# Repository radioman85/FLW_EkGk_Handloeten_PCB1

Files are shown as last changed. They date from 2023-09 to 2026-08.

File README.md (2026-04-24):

### Präsentation
[FabLab - Handlötkurs 02-2025.pdf](https://github.com/user-attachments/files/19078771/FabLab.-.Handlotkurs.02-2025.pdf)

### BOM

Currently unavailable

### Programming Pi Pico

## Preparation

1. Download, install and run the [thonny app](https://thonny.org/)
2. Connect the pico
3. In the Thonny app on the right bottom corner you can see your connected pico. From there install the micro python firmware

## Python Script
1. Once the pico has received its micro python firmware click on the "Stop" button on top of the thonny app.
5. Load the script you want to download to the raspi.
6. Go to "Save as", where it asks for either save on PC or on Raspberry (if not asked, the raspberry is not connected correctly (its firmware may not be up-to-date)).
7. Select "Raspberry Pi".
8. Save it as "main.py" (it must be named as "main" else it wont auto-start after reboot)
9. Happy running :-)

### Löten - Ausrüstung

 - Lötkolben (Link: [JBC CD-2BQF](https://shop.electronic-metals.ch/produkte/loettechnik/loetgeraete-ein-kanal/jbc/94951/jbc-kompakt-loetstation-cd-2bqf-wetec-edition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), Handle (included): [T245](https://www.jbctools.com/t245-general-purpose-handle-product-45.html) , Spitzen (NOT included): [C245-030](https://shop.electronic-metals.ch/produkte/loettechnik/loet-entloetspitzen/jbc/c245-fuer-t245/rundform/8647/jbc-loetspitze-serie-c245-rundform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), -034, -906)
 - Lötzinn + Paste
    - 63% (Sn), 37% (Pb) (Link: [Lötdraht 0.7 mm](https://ch.farnell.com/multicore-loctite/d610scf222-250g/l-tdraht-60-40-0-7mm-250g/dp/454072), Link: [Paste - Chip Quik SMD291AX](https://ch.farnell.com/chip-quik/smd291ax/l-tpaste-no-clean-synthetisch/dp/3549310)) oder
    - 95,5% (Sn), 3,8% (Ag), 0,7% (Cu) (Link: [Lötdraht 0.7 mm](https://ch.farnell.com/multicore-loctite/d96scf222-250g/l-tdraht-105-0-7mm-250g/dp/454590), Link: [Chip Quik TS391SNL](https://ch.farnell.com/chip-quik/ts391snl/l-tpaste-no-clean-synthetisch/dp/3549323))
 - Lötflussmittel (Link: [Chip Quik SMD291](https://www.mouser.ch/ProductDetail/Chip-Quik/SMD291?qs=8BX3xQzFIvmwkympZqnNNA%3D%3D))
 - Lötmatte
 - Pinzetten (Link: [Weller Erem 7SASL, gebogen](https://ch.farnell.com/erem/7sasl/pr-zisionspinzette-gebogen-spitz/dp/2946763), Link: [Weller Erem 3SASL, gerade](https://ch.farnell.com/erem/3sasl/pinzette-120mm/dp/1014352))
 - Zahbüsrteli / Wattestäbli (Link: [M-Budget Zahnbürste](https://www.migros.ch/de/product/mo/96751))
 - Fläschli Isopropanol (Link: [Isopropanol 99,9 %](https://www.gerstaecker.ch/Isopropanol-99-9.html))
 - Shimblade (Link: [EDSYN - ST706](https://ch.farnell.com/edsyn/st706/halter-f-r-entl-tklingen/dp/844457), Ersatzklingen (Link: [EDSYN - RB641](https://ch.farnell.com/edsyn/rb641/entl-tklingen-zuschneidbares-stahlband/dp/844445))
 - Tip Tinner/Cleaner/Activator (Link: [Weller Tip Activater](https://www.simpex.ch/shop/produktionstechnik/loetzubehoer/tip-aktivator-bleifrei/?gad_campaignid=22242456144))

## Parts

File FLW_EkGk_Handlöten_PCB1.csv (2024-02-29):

Source: | C:\98-Others\FLW_EkGk_Handloeten_PCB1\FLW_EkGk_Handlöten_PCB1.kicad_sch
Date: | 21-Nov-23 21:35:43
Tool: | Eeschema 7.0.1
Generator: | C:\Program Files\KiCad\7.0\bin\scripting\plugins/bom_csv_grouped_by_value.py
Component Count: | 110
Collated Components:
Item | Qty | Reference(s) | Value | LibPart | Footprint | Datasheet | DNP | Country of Origin | Function | Height | Manufacturer_Name | Manufacturer_Part_Number | Mouser Part Number | Mouser Price/Stock | Voltage
1 | 2 | C61, C62 | 100n | Device:C | Capacitor_SMD:C_1206_3216Metric | ~
2 | 1 | IC60 | HCF4094YM013TR | :HCF4094YM013TR_1 | NiksKiCadLibrary:SOIC-16-SOIC127P600X175-16N | http://www.st.com/st-web-ui/static/active/en/resource/technical/document/datasheet/CD00000399.pdf |  |  |  | 1.75 | STMicroelectronics | HCF4094YM013TR | 511-HCF4094YM013TR | https://www.mouser.co.uk/ProductDetail/STMicroelectronics/HCF4094YM013TR?qs=wkiPY8TIIKfZLRSu0KejOg%3D%3D | Vin: 3 ... 20 V
3 | 1 | IC61 | HCF4094YM013TR | NiksKiCadLibrary:HCF4094YM013TR | NiksKiCadLibrary:SOIC-16-SOIC127P600X175-16N | http://www.st.com/st-web-ui/static/active/en/resource/technical/document/datasheet/CD00000399.pdf |  |  |  | 1.75 | STMicroelectronics | HCF4094YM013TR | 511-HCF4094YM013TR | https://www.mouser.co.uk/ProductDetail/STMicroelectronics/HCF4094YM013TR?qs=wkiPY8TIIKfZLRSu0KejOg%3D%3D | Vin: 3 ... 20 V
4 | 4 | J10, J11, J12, J13 | Conn_01x02 | Connector_Generic:Conn_01x02 | Connector_PinHeader_2.54mm:PinHeader_1x02_P2.54mm_Horizontal | ~
5 | 13 | LED60, LED61, LED62, LED63, LED64, LED65, LED69, LED70, LED71, LED72, LED73, LED74, LED75 | SML-LX1206SIC-TR | FabLabWintiLibrary:SML-LX1206SIC-TR | FabLabWintiLibrary:LED_SML-LX1206SIC-TR_LUM | SML-LX1206SIC-TR
6 | 3 | LED66, LED67, LED68 | LTST-E563CEGBW | NiksKiCadLibrary:LTST-E563CEGBW | NiksKiCadLibrary:LTSTE563CEGBW | https://optoelectronics.liteon.com/upload/download/DS35-2018-0038/LTST-E563CEGBW.PDF |  | China |  | 1.62 | Lite-On | LTST-E563CEGBW | 859-LTST-E563CEGBW
7 | 13 | Q60, Q61, Q62, Q63, Q64, Q65, Q66, Q67, Q68, Q69, Q70, Q71, Q72 | 2N7002 | Transistor_FET:2N7002 | Package_TO_SOT_SMD:SOT-23 | https://www.onsemi.com/pub/Collateral/NDS7002A-D.PDF
8 | 33 | R10, R11, R12, R13, R14, R15, R16, R17, R18, R19, R30, R31, R32, R33, R34, R35, R36, R37, R38, R39, R60, R61, R62, R63, R64, R65, R67, R68, R69, R70, R71, R72, R73 | R | Device:R | Resistor_SMD:R_1206_3216Metric | ~
9 | 20 | R20, R21, R22, R23, R24, R25, R26, R27, R28, R29, R40, R41, R42, R43, R44, R45, R46, R47, R48, R49 | R | Device:R | Resistor_SMD:R_0805_2012Metric | ~
10 | 2 | R66, R74 | 330R | Device:R | Resistor_SMD:R_1206_3216Metric | ~
11 | 4 | R75, R76, R77, R78 | 10k | Device:R | Resistor_SMD:R_1206_3216Metric | ~
12 | 1 | SW60 | MSS6-V-T_R | NiksKiCadLibrary:MSS6-V-T_R | NiksKiCadLibrary:MSS6VTR | http://www.dip.com.tw/en/en-product-information/en-switch005/item/download/2644_d484074ddae8110c965b39aa743c4160 |  |  | Power Enable | 2.9 | Diptronics | MSS6-V-T/R | 113-MSS6-V-T/R | https://www.mouser.co.uk/ProductDetail/Diptronics/MSS6-V-T-R?qs=gTYE2QTfZfT81btvsnXi7w%3D%3D
13 | 1 | SW61 | B3U-3100P | :B3U-3100P_1 | SW_B3U-3100P_OMR | B3U-3100P |  |  | Manual Clock
14 | 1 | SW62 | B3U-3100P | NiksKiCadLibrary:B3U-3100P | SW_B3U-3100P_OMR | B3U-3100P |  |  | Manual Data
15 | 10 | TP60, TP61, TP62, TP63, TP64, TP65, TP66, TP67, TP68, TP69 | TestPoint | Connector:TestPoint | NiksKiCadLibrary:TestPointSimpleSMD | ~
16 | 1 | U2 | RPi-Pico | FabLabWintiLibrary:RPi-Pico | FabLabWintiLibrary:RPi_Pico_SMD_TH

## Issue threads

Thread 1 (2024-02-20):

RGB-LED Footprint too small

radioman85, 2024-02-20:

Closed 2024-02-29.

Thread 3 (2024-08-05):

RGB LED: Missing Pin Mark

radioman85, 2024-08-05:

Closed 2024-09-02.

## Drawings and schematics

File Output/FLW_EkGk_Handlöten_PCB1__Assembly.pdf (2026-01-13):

LED0 Data | þÿLötkurs - | þÿHandlöten
1 | 3 | 4 Clock PulsePraxis 1 - | Erste | þÿLötstellen

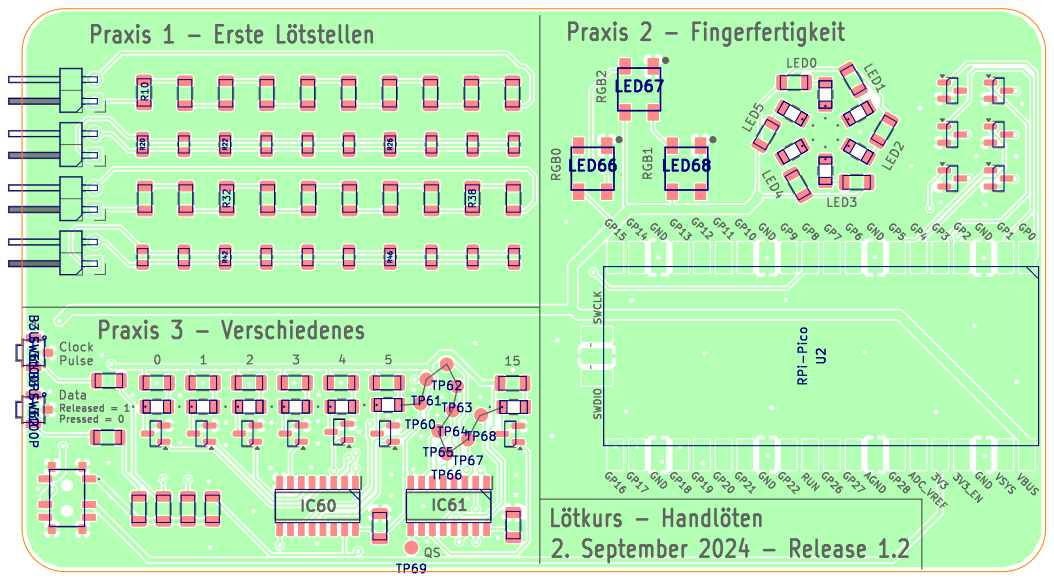
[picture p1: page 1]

Id: /1 Title: File: þÿFLW_EkGk_Handlöten_PCB1.kicad_pcb Sheet: Colored TOP

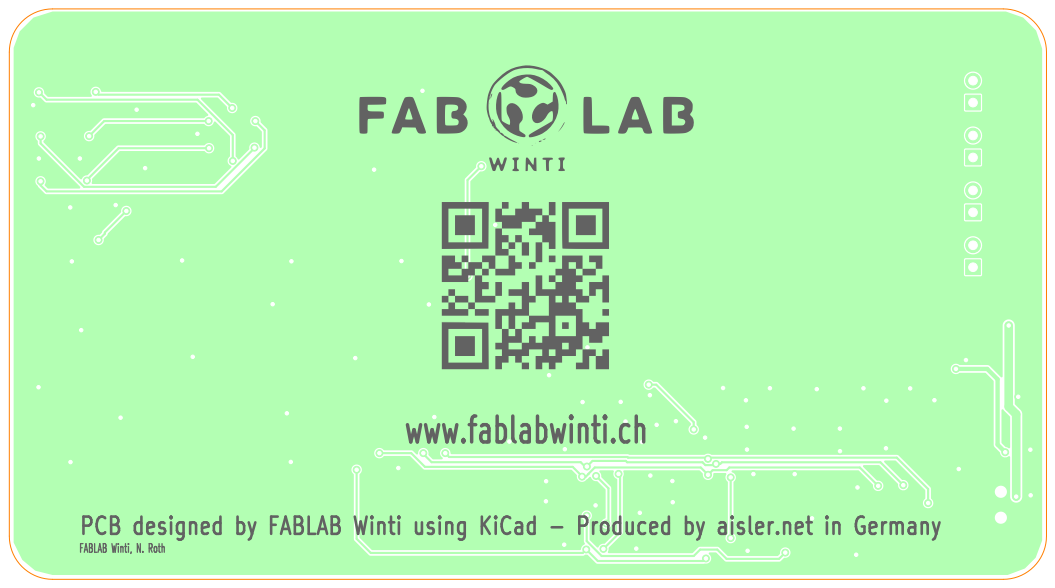
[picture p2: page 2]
PCB designed; FABLAB; Winti using KiCad; Produced by; aisler.net in Germany; FABLAB Winti, N. Roth; www.fablabwinti.ch; D Date: KiCad; E.D.A. 9.0.0 Size: A4; Rev:; Id: /1 Title: File: þÿFLW_EkGk_Handlöten_PCB1.kicad_pcb Sheet: Colored; BOT Board2Pdf:; Colored; BOT -; Page 2/2

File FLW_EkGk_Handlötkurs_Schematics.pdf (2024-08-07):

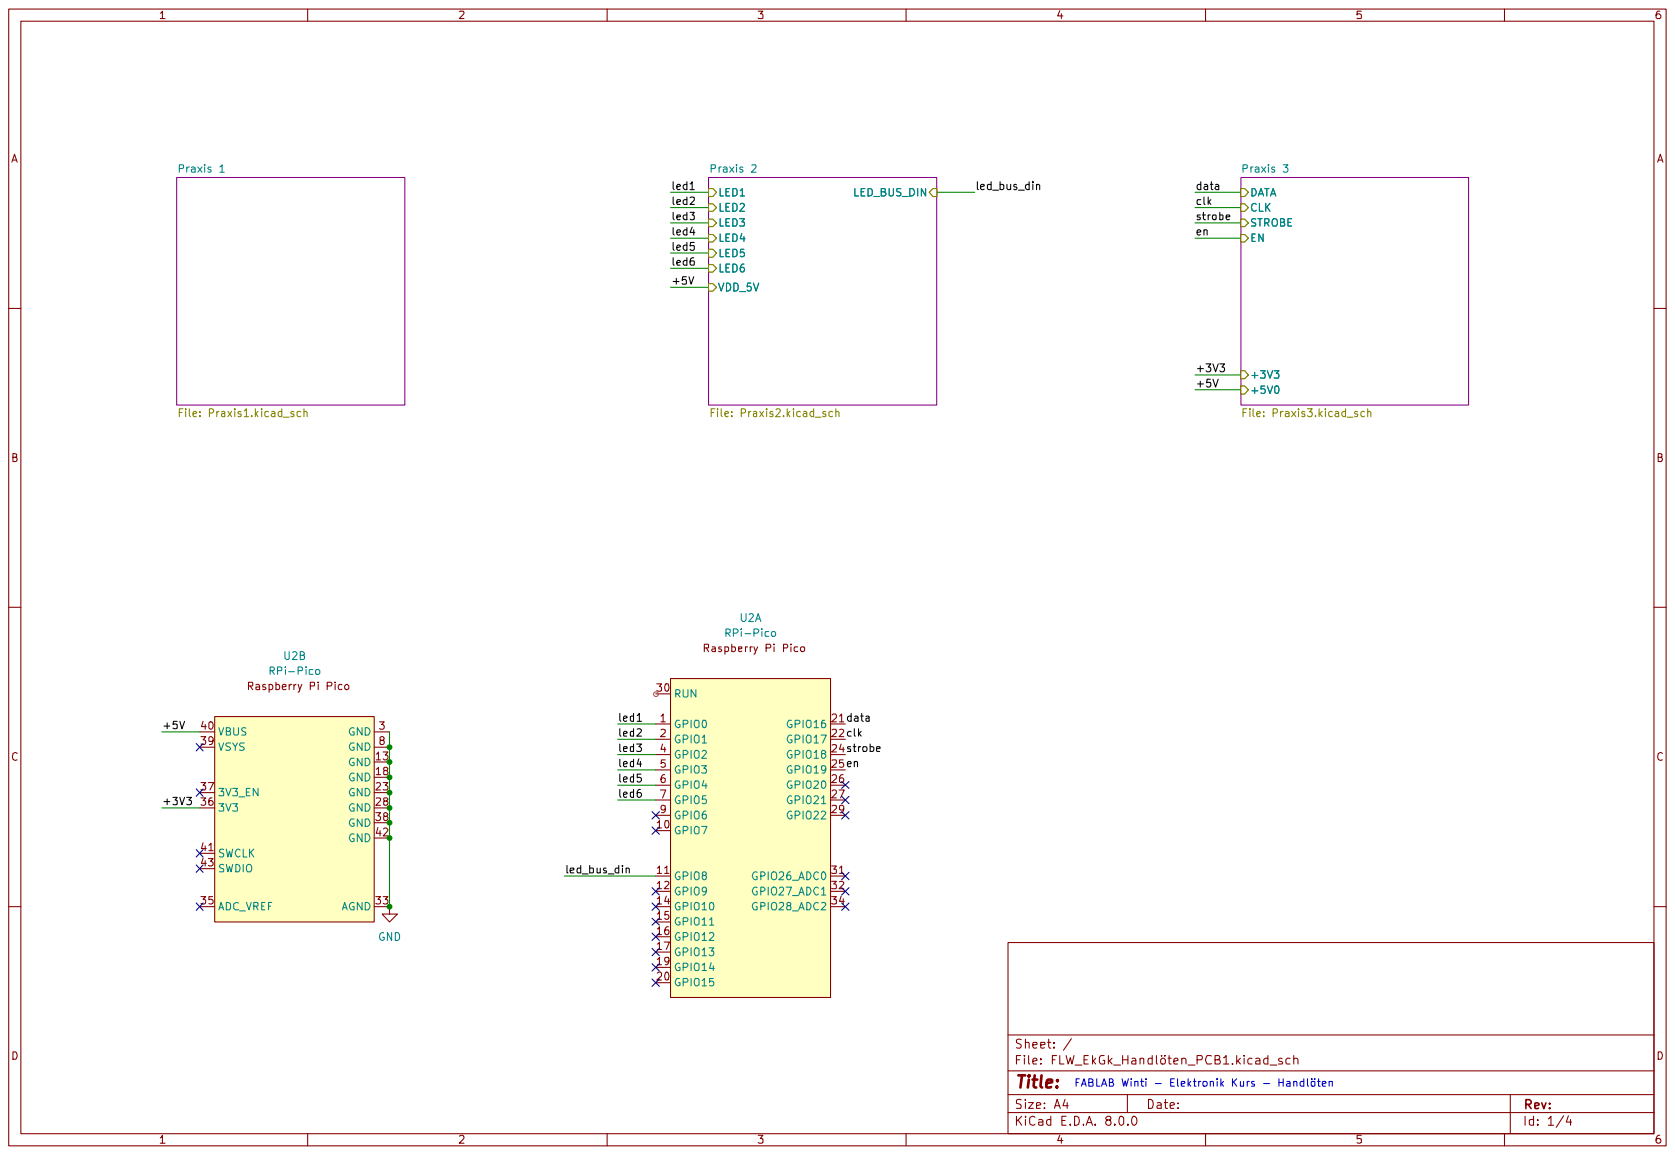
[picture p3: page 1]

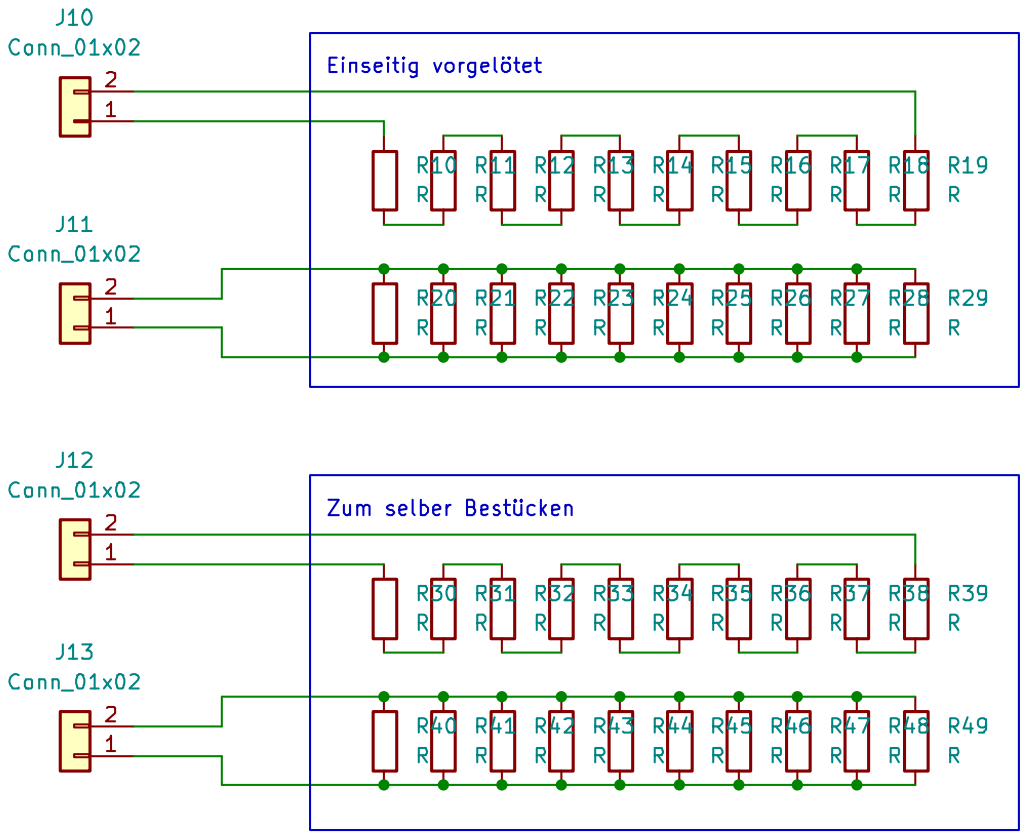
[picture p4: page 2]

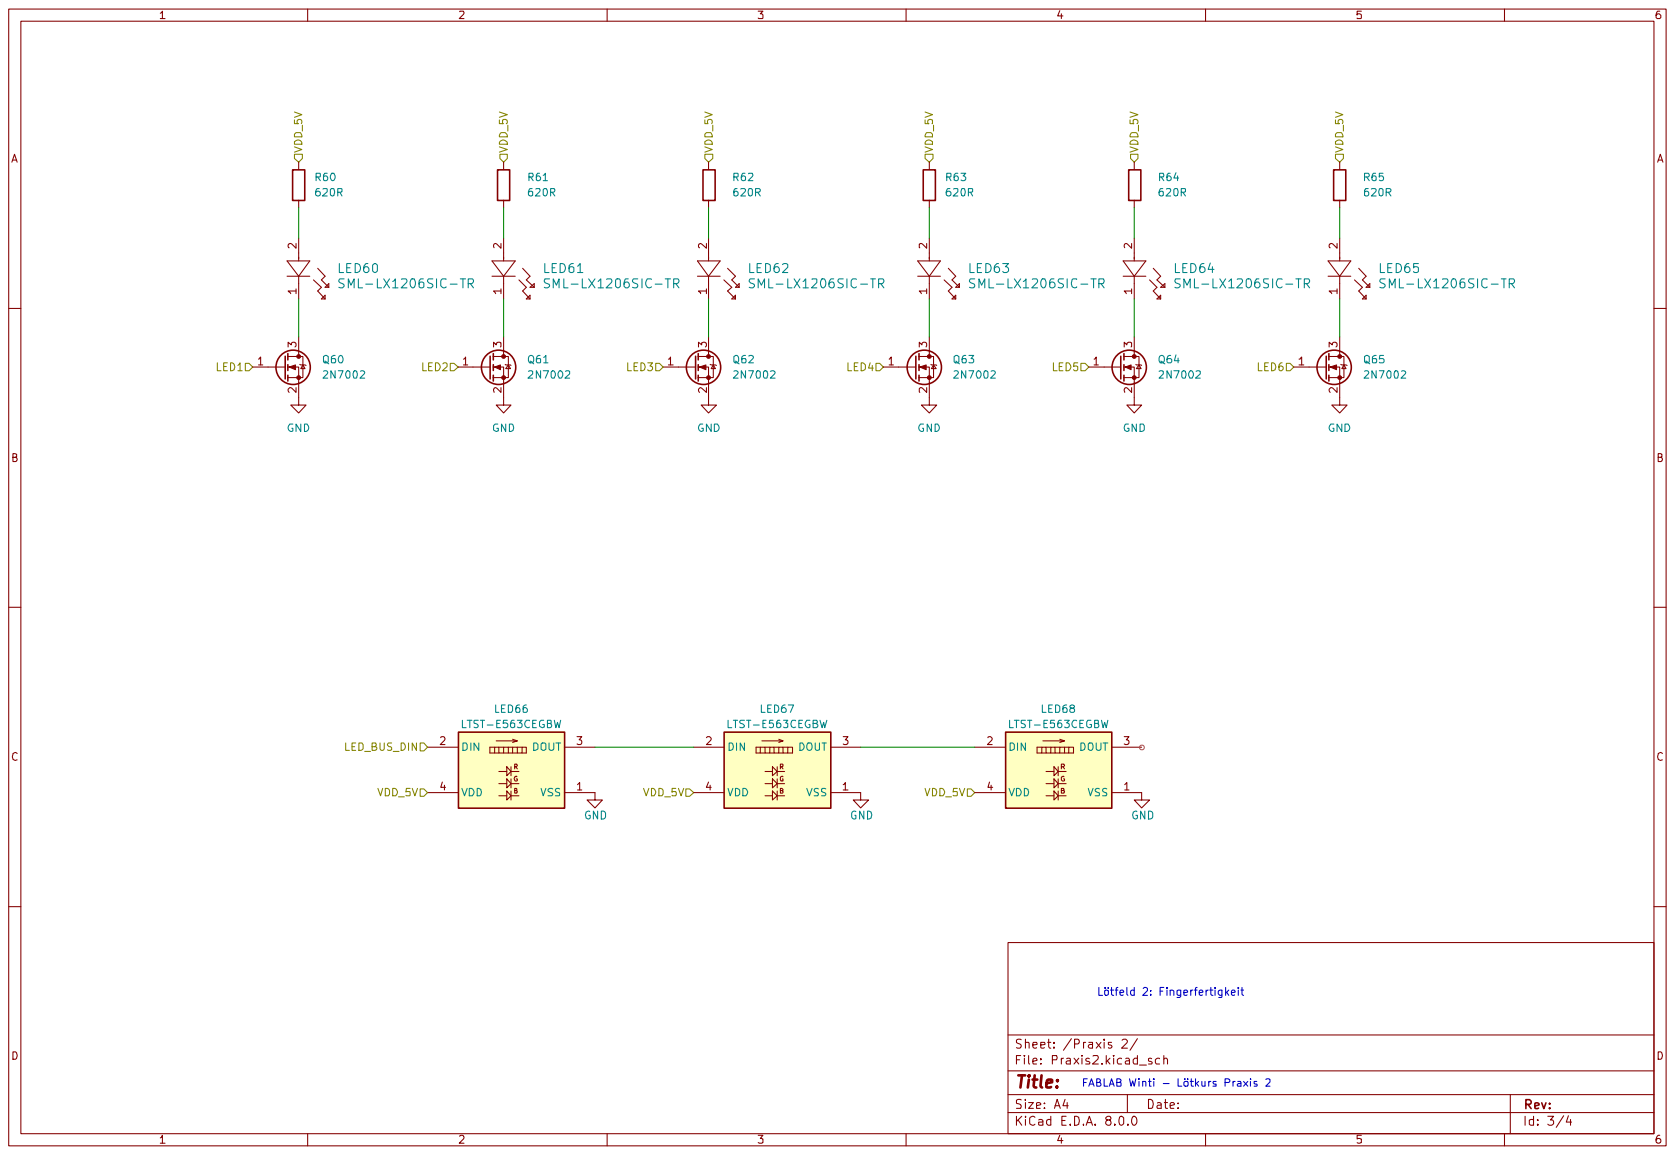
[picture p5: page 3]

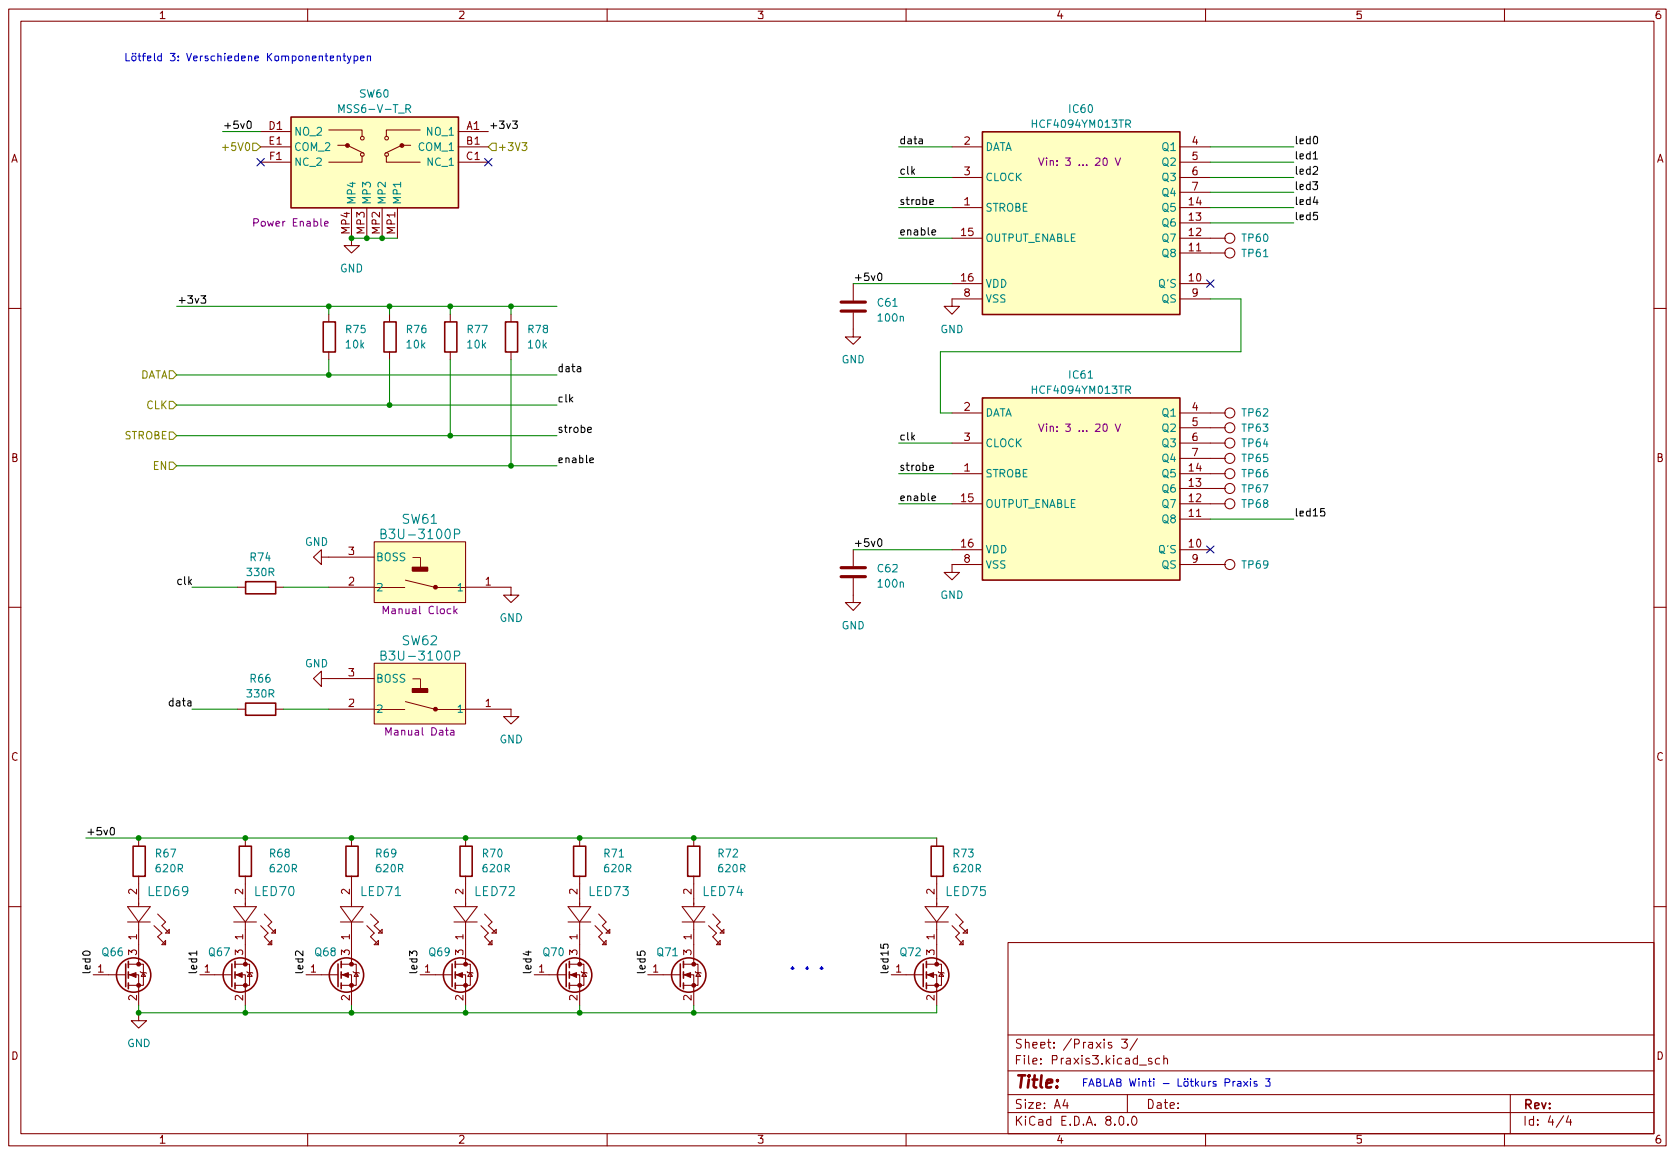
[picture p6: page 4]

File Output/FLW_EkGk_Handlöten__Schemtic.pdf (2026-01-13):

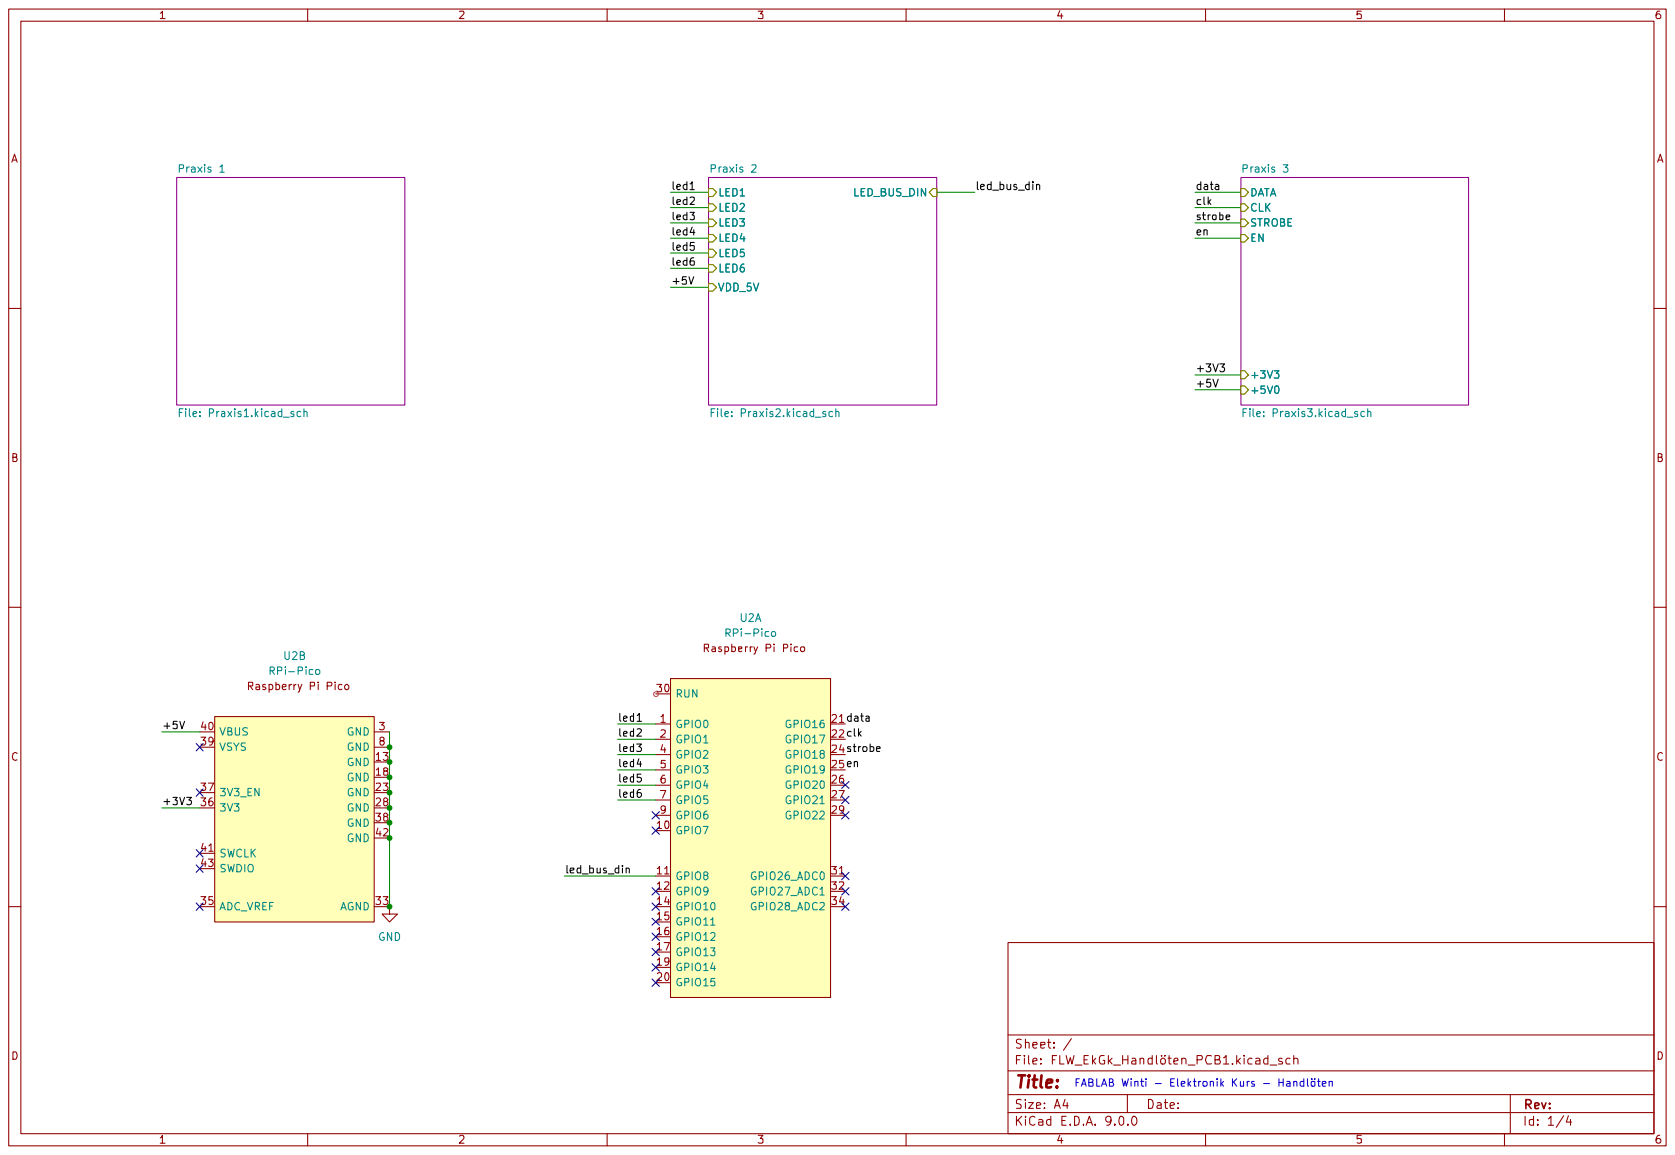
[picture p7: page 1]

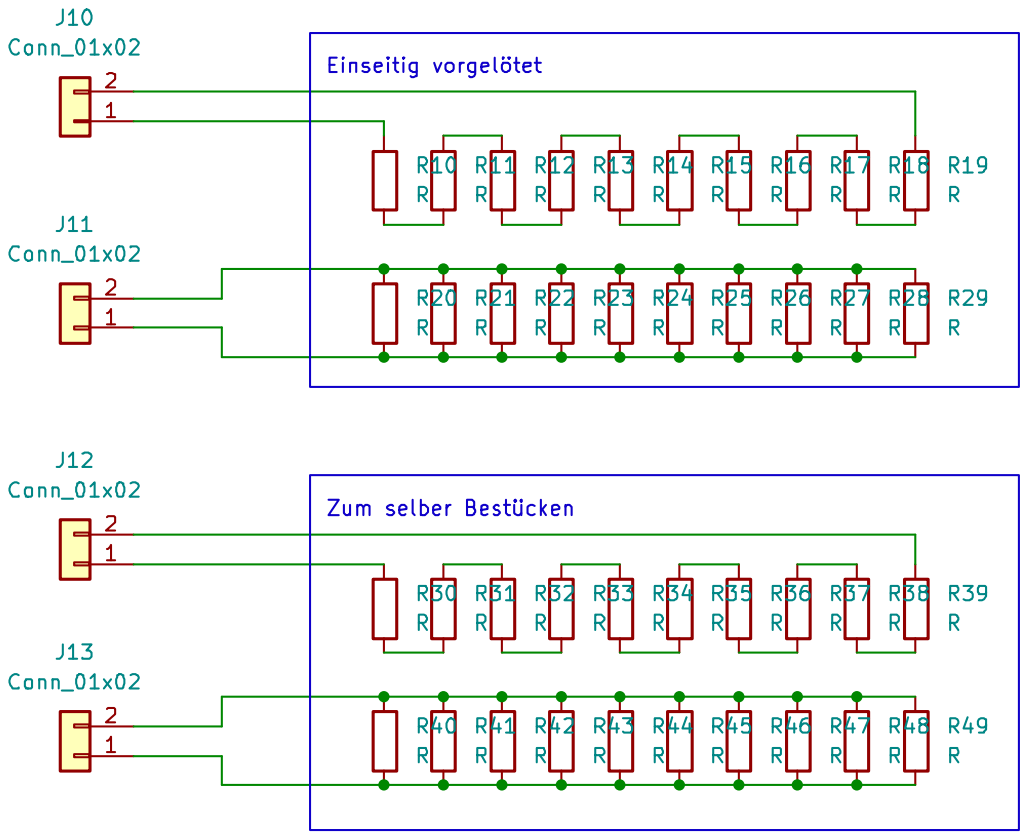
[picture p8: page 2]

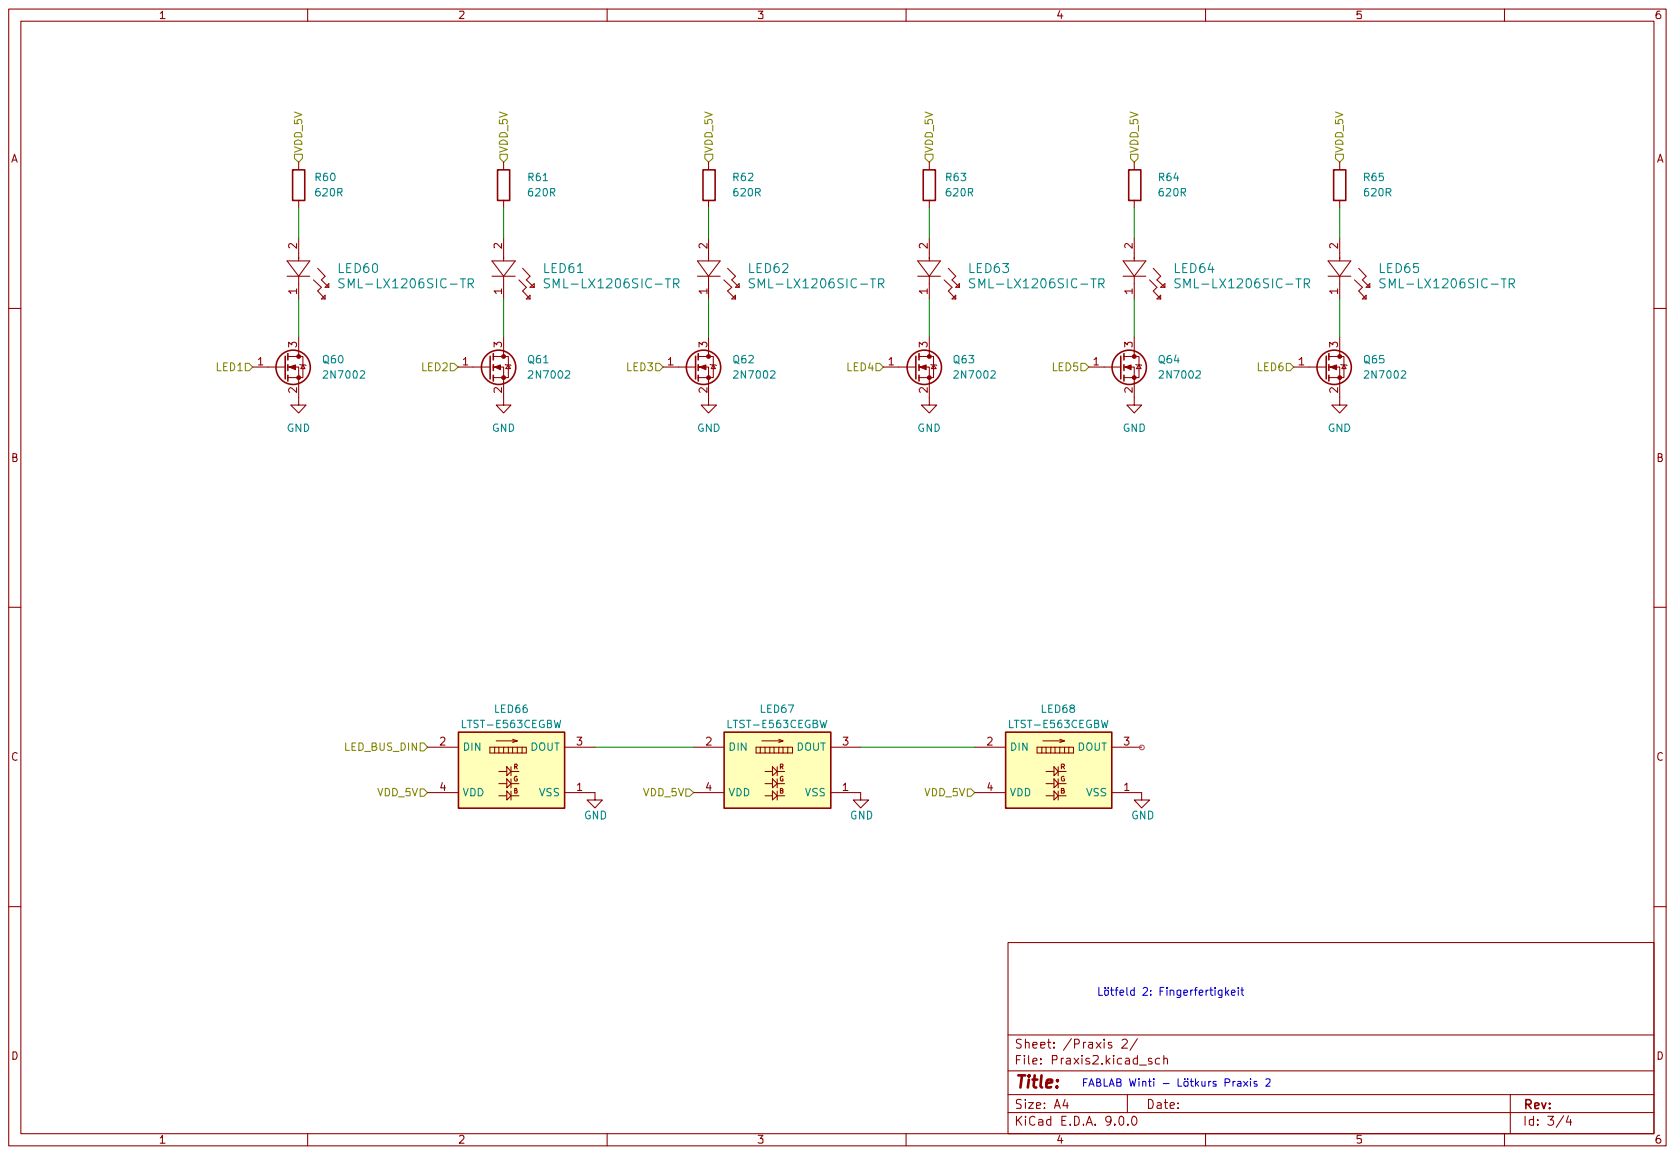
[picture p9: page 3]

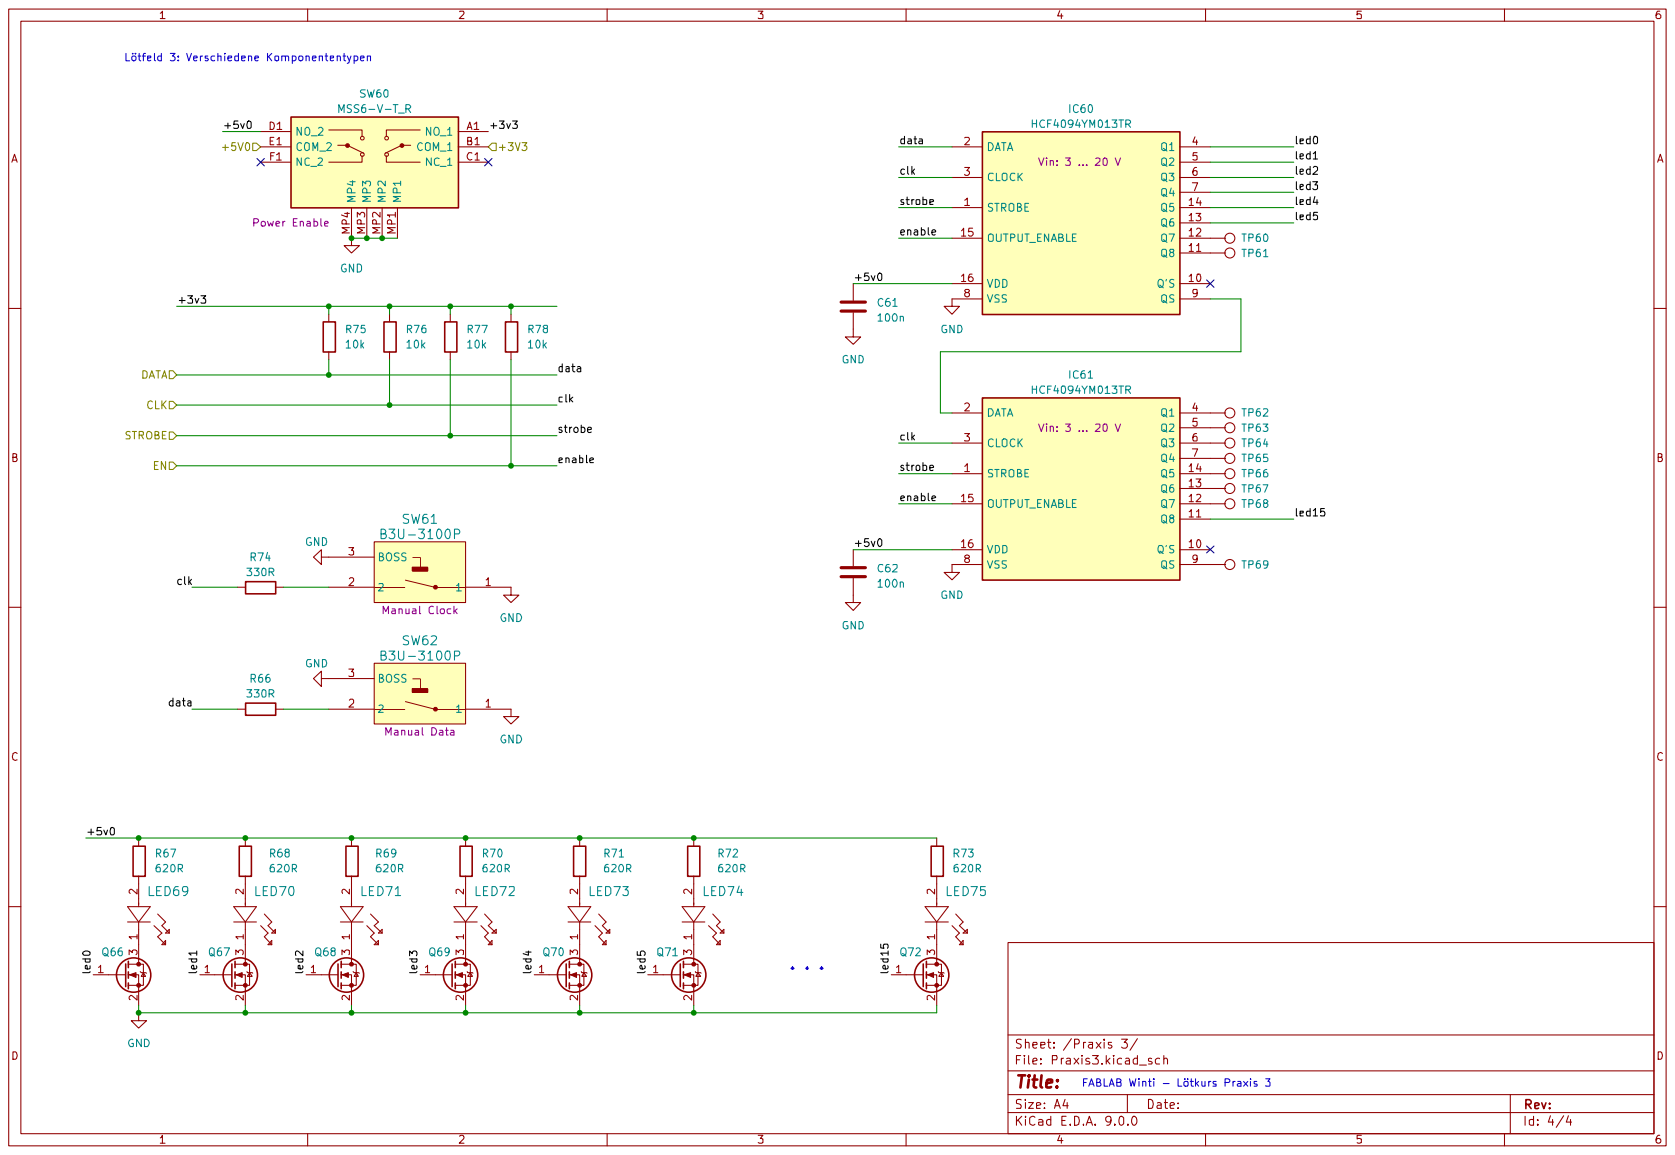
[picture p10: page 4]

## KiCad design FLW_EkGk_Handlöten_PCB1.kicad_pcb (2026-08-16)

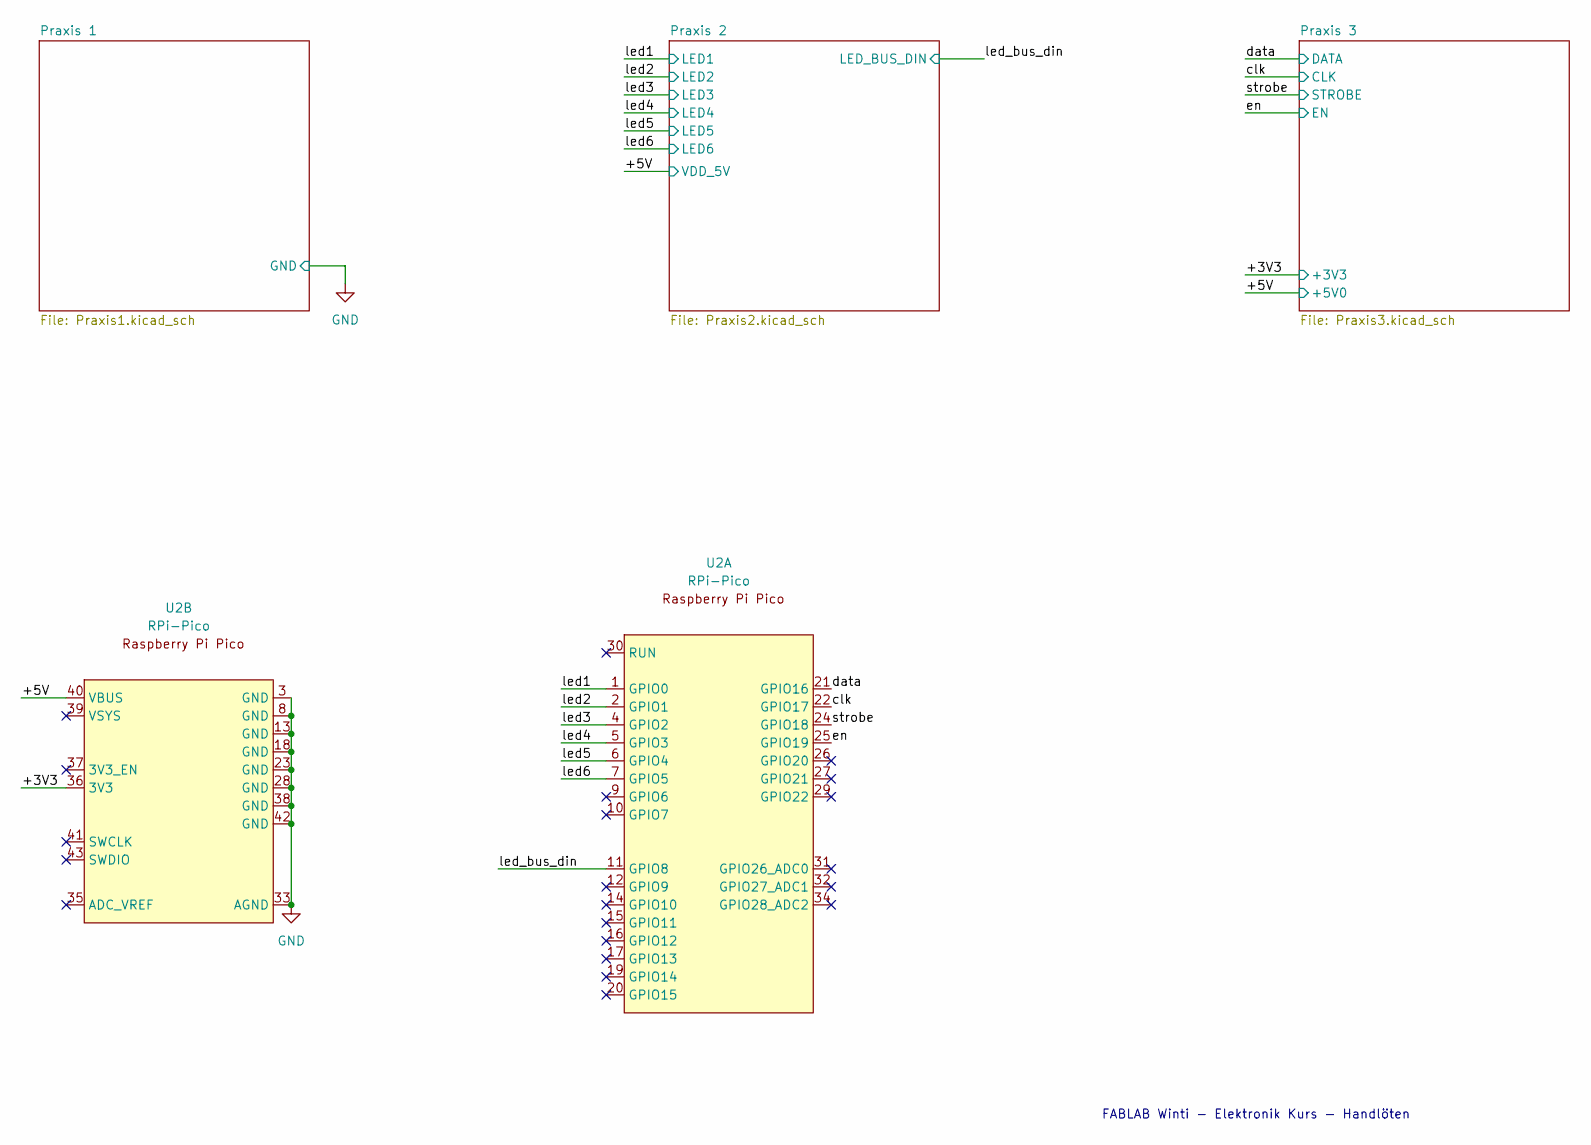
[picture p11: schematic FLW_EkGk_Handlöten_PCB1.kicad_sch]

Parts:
U2: RPi-Pico; RPi_Pico_SMD_TH

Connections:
/+3V3: U2.36 (3V3); also elsewhere on the board
/+5V: U2.40 (VBUS); also elsewhere on the board
/clk: U2.22 (GPIO17); also elsewhere on the board
/data: U2.21 (GPIO16); also elsewhere on the board
/en: U2.25 (GPIO19); also elsewhere on the board
/led1: U2.1 (GPIO0); also elsewhere on the board
/led2: U2.2 (GPIO1); also elsewhere on the board
/led3: U2.4 (GPIO2); also elsewhere on the board
/led4: U2.5 (GPIO3); also elsewhere on the board
/led5: U2.6 (GPIO4); also elsewhere on the board
/led6: U2.7 (GPIO5); also elsewhere on the board
/led_bus_din: U2.11 (GPIO8); also elsewhere on the board
/strobe: U2.24 (GPIO18); also elsewhere on the board
GND: U2.3 (GND), U2.8 (GND), U2.13 (GND), U2.18 (GND), U2.23 (GND), U2.28 (GND), U2.33 (AGND), U2.38 (GND), U2.42 (GND); also elsewhere on the board

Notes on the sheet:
FABLAB Winti - Elektronik Kurs - Handlöten

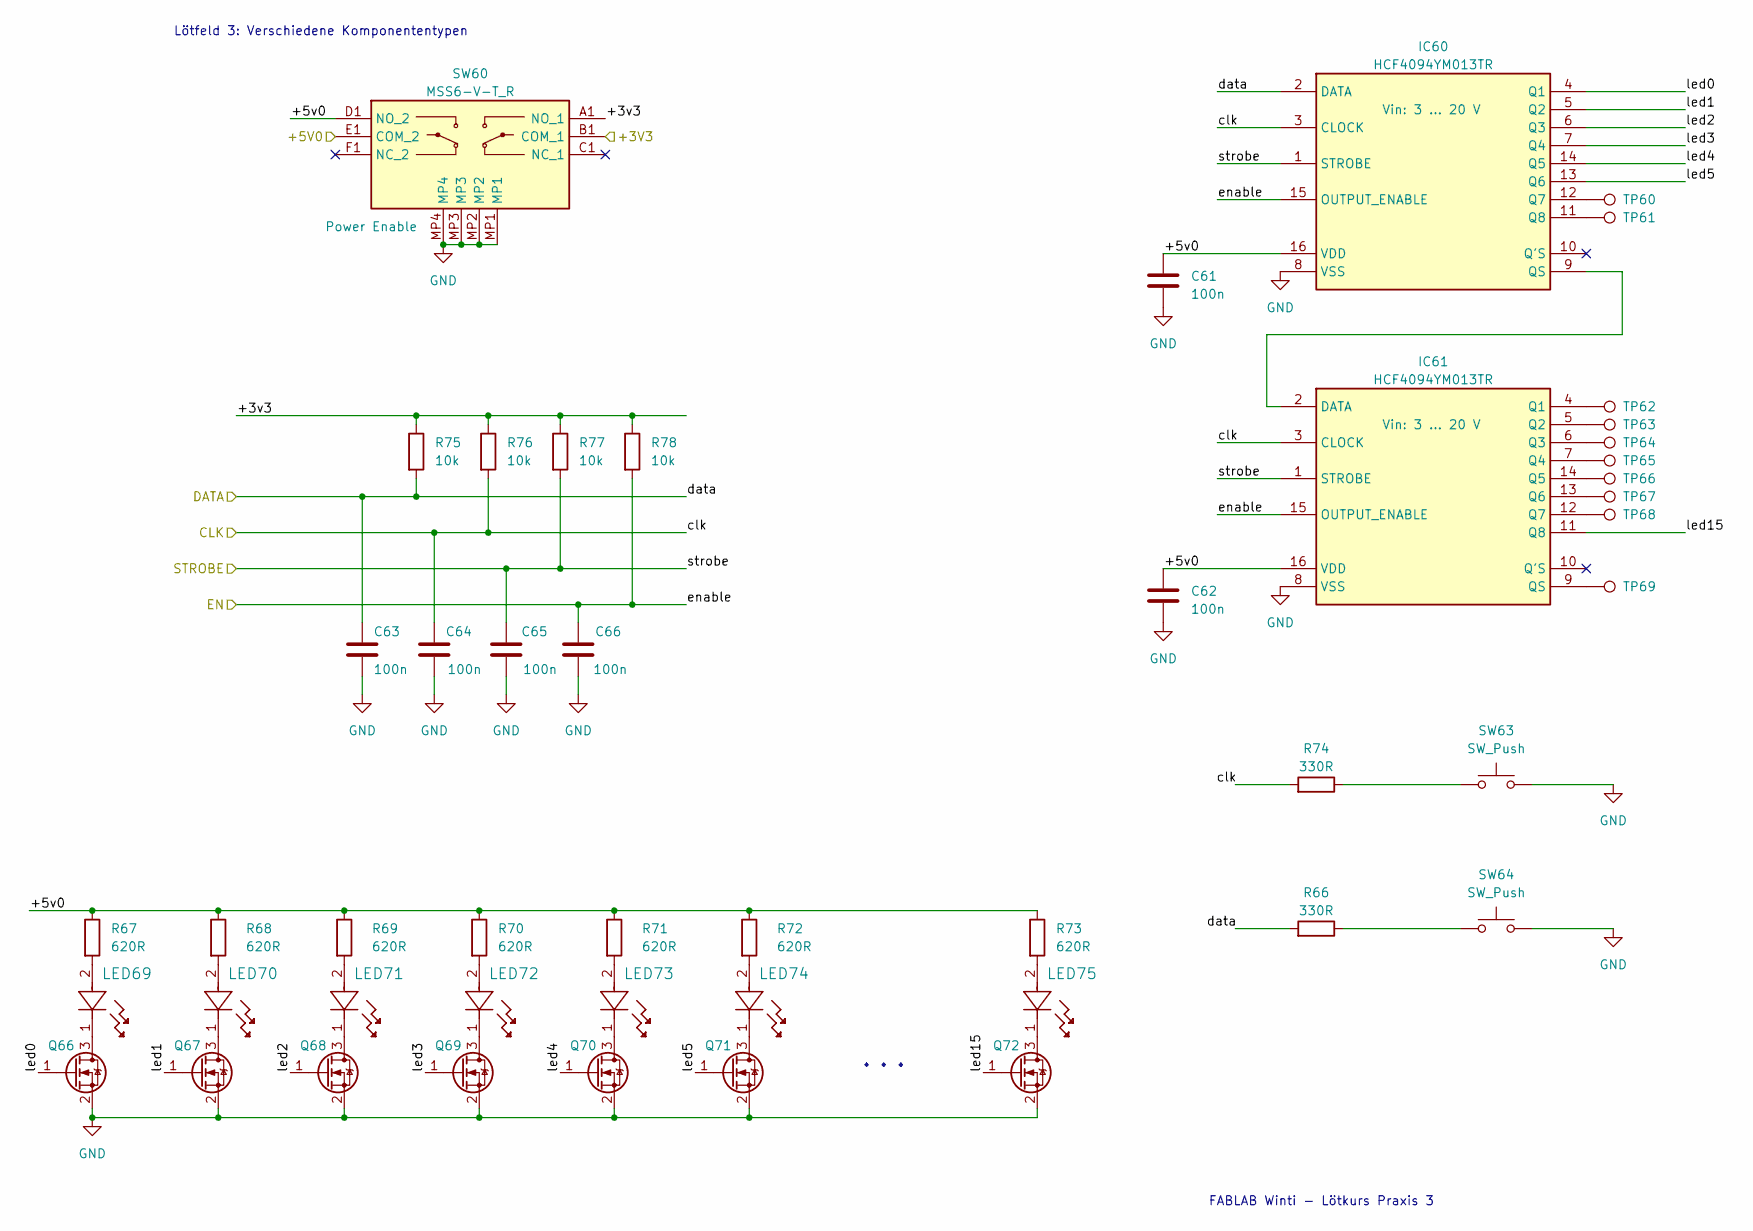
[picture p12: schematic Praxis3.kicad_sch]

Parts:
C61, C62, C63, C64, C65, C66: 100n; C_1206_3216Metric
IC60, IC61: HCF4094YM013TR; SOIC-16-SOIC127P600X175-16N; Voltage Vin: 3 ... 20 V; Mouser Part Number 511-HCF4094YM013TR
LED69, LED70, LED71, LED72, LED73, LED74, LED75: SML-LX1206SIC-TR; LED_SML-LX1206SIC-TR_LUM
Q66, Q67, Q68, Q69, Q70, Q71, Q72: 2N7002; SOT-23
R66, R74: 330R; R_1206_3216Metric
R67, R68, R69, R70, R71, R72, R73: 620R; R_1206_3216Metric
R75, R76, R77, R78: 10k; R_1206_3216Metric
SW60: MSS6-V-T_R; MSS6VTR; Mouser Part Number 113-MSS6-V-T/R
SW63, SW64: SW_Push; SW_Push_1P1T_NO_CK_KSC7xxJ
TP60, TP61, TP62, TP63, TP64, TP65, TP66, TP67, TP68, TP69: TestPoint; TestPointSimpleSMD

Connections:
/+3V3: SW60.B1 (COM_1); also elsewhere on the board
/+5V: SW60.E1 (COM_2); also elsewhere on the board
/Praxis 3/+3v3: R75.1, R76.1, R77.1, R78.1, SW60.A1 (NO_1)
/Praxis 3/+5v0: C61.1, C62.1, IC60.16 (VDD), IC61.16 (VDD), R67.1, R68.1, R69.1, R70.1, R71.1, R72.1, R73.1, SW60.D1 (NO_2)
/Praxis 3/led0: IC60.4 (Q1), Q66.1 (G)
/Praxis 3/led1: IC60.5 (Q2), Q67.1 (G)
/Praxis 3/led2: IC60.6 (Q3), Q68.1 (G)
/Praxis 3/led3: IC60.7 (Q4), Q69.1 (G)
/Praxis 3/led4: IC60.14 (Q5), Q70.1 (G)
/Praxis 3/led5: IC60.13 (Q6), Q71.1 (G)
/Praxis 3/led15: IC61.11 (Q8), Q72.1 (G)
/clk: C64.1, IC60.3 (CLOCK), IC61.3 (CLOCK), R74.2, R76.2; also elsewhere on the board
/data: C63.1, IC60.2 (DATA), R66.2, R75.2; also elsewhere on the board
/en: C66.1, IC60.15 (OUTPUT_ENABLE), IC61.15 (OUTPUT_ENABLE), R78.2; also elsewhere on the board
/strobe: C65.1, IC60.1 (STROBE), IC61.1 (STROBE), R77.2; also elsewhere on the board
GND: C61.2, C62.2, C63.2, C64.2, C65.2, C66.2, IC60.8 (VSS), IC61.8 (VSS), Q66.2 (S), Q67.2 (S), Q68.2 (S), Q69.2 (S), Q70.2 (S), Q71.2 (S), Q72.2 (S), SW60.MP1, SW60.MP2, SW60.MP3, SW60.MP4, SW63.2, SW64.2; also elsewhere on the board
unnamed: IC60.12 (Q7), TP60.1 (1_1)
unnamed: IC60.11 (Q8), TP61.1 (1_1)
unnamed: IC60.9 (QS), IC61.2 (DATA)
unnamed: IC61.4 (Q1), TP62.1 (1_1)
unnamed: IC61.5 (Q2), TP63.1 (1_1)
unnamed: IC61.6 (Q3), TP64.1 (1_1)
unnamed: IC61.7 (Q4), TP65.1 (1_1)
unnamed: IC61.14 (Q5), TP66.1 (1_1)
unnamed: IC61.13 (Q6), TP67.1 (1_1)
unnamed: IC61.12 (Q7), TP68.1 (1_1)
unnamed: IC61.9 (QS), TP69.1 (1_1)
unnamed: LED69.2, R67.2
unnamed: LED70.2, R68.2
unnamed: LED71.2, R69.2
unnamed: LED72.2, R70.2
unnamed: LED73.2, R71.2
unnamed: LED74.2, R72.2
unnamed: LED75.2, R73.2
unnamed: LED69.1, Q66.3 (D)
unnamed: LED70.1, Q67.3 (D)
unnamed: LED71.1, Q68.3 (D)
unnamed: LED72.1, Q69.3 (D)
unnamed: LED73.1, Q70.3 (D)
unnamed: LED74.1, Q71.3 (D)
unnamed: LED75.1, Q72.3 (D)
unnamed: R66.1, SW64.1
unnamed: R74.1, SW63.1

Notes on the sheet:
FABLAB Winti - Lötkurs Praxis 3
Lötfeld 3: Verschiedene Komponententypen
...

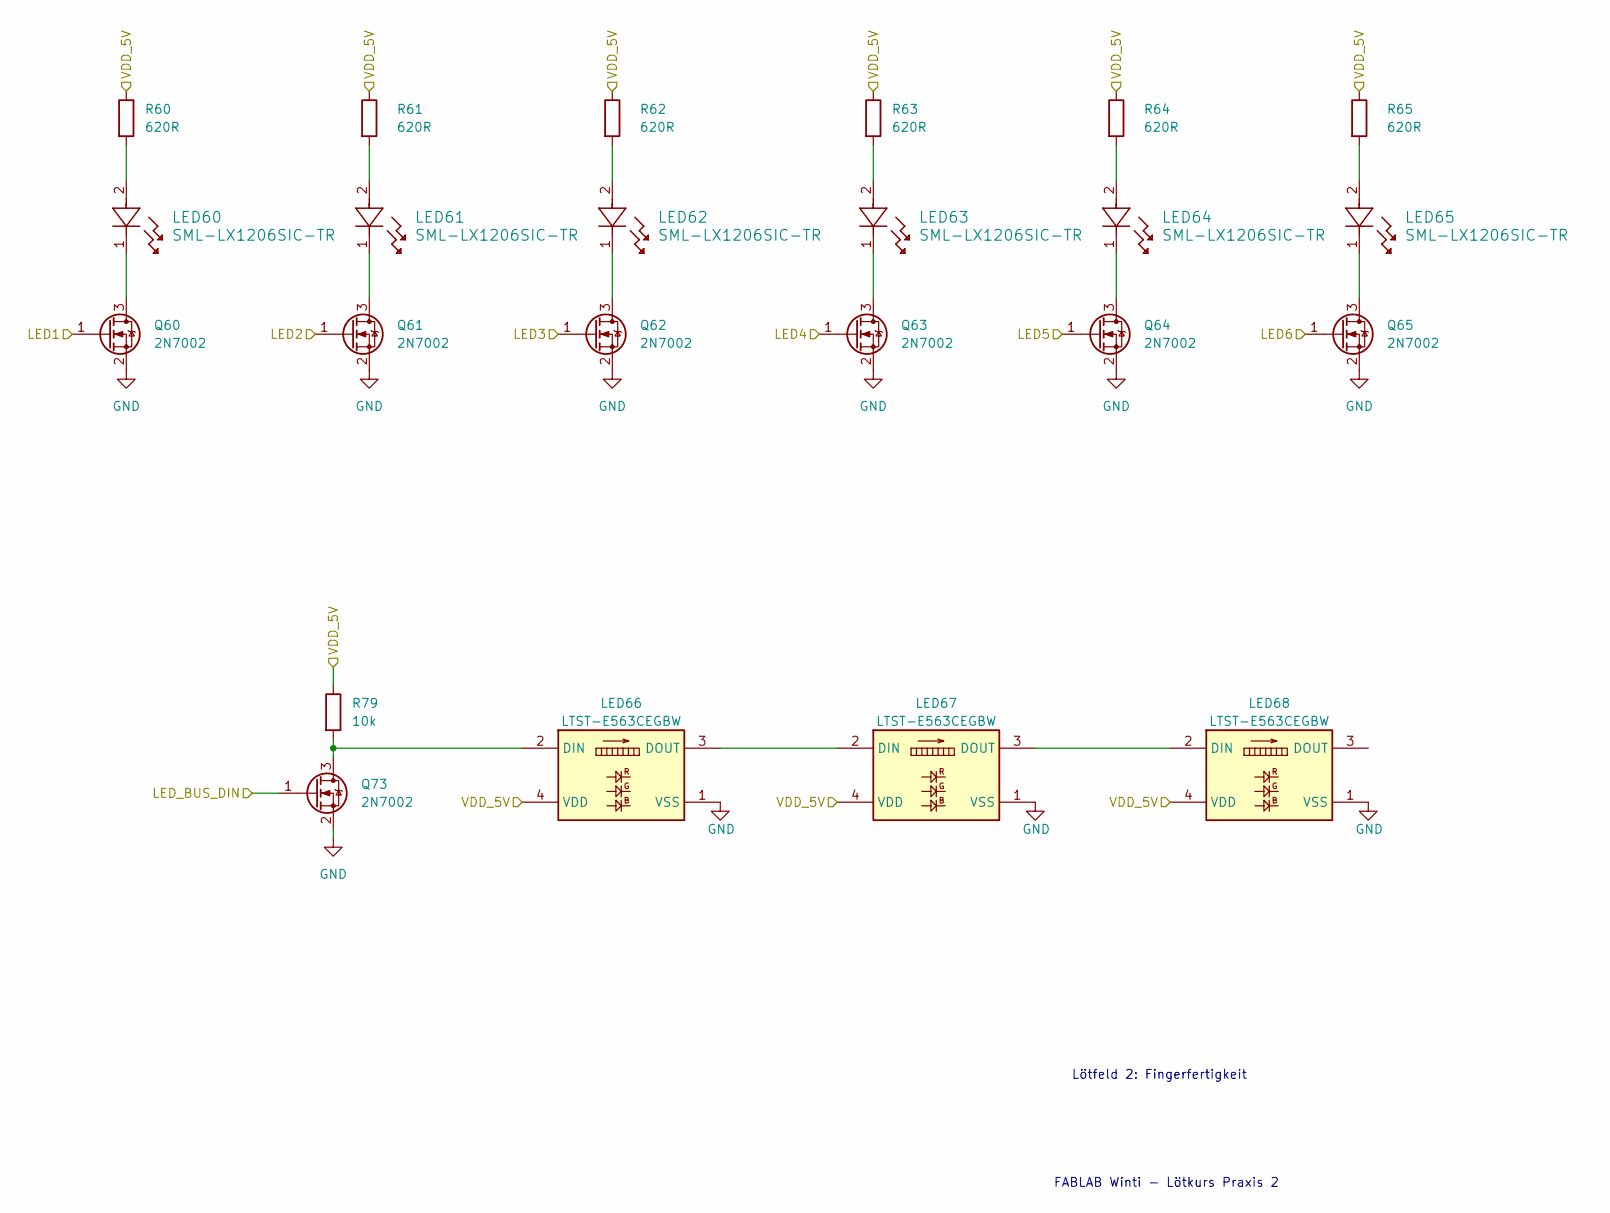
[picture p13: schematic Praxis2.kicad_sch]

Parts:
LED60, LED61, LED62, LED63, LED64, LED65: SML-LX1206SIC-TR; LED_SML-LX1206SIC-TR_LUM
LED66, LED67, LED68: LTST-E563CEGBW; LTSTE563CEGBW; Mouser Part Number 859-LTST-E563CEGBW
Q60, Q61, Q62, Q63, Q64, Q65, Q73: 2N7002; SOT-23
R60, R61, R62, R63, R64, R65: 620R; R_1206_3216Metric
R79: 10k; R_1206_3216Metric

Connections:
/+5V: LED66.4 (VDD), LED67.4 (VDD), LED68.4 (VDD), R60.1, R61.1, R62.1, R63.1, R64.1, R65.1, R79.1; also elsewhere on the board
/led1: Q60.1 (G); also elsewhere on the board
/led2: Q61.1 (G); also elsewhere on the board
/led3: Q62.1 (G); also elsewhere on the board
/led4: Q63.1 (G); also elsewhere on the board
/led5: Q64.1 (G); also elsewhere on the board
/led6: Q65.1 (G); also elsewhere on the board
/led_bus_din: Q73.1 (G); also elsewhere on the board
GND: LED66.1 (VSS), LED67.1 (VSS), LED68.1 (VSS), Q60.2 (S), Q61.2 (S), Q62.2 (S), Q63.2 (S), Q64.2 (S), Q65.2 (S), Q73.2 (S); also elsewhere on the board
unnamed: LED60.2, R60.2
unnamed: LED61.2, R61.2
unnamed: LED62.2, R62.2
unnamed: LED63.2, R63.2
unnamed: LED64.2, R64.2
unnamed: LED65.2, R65.2
unnamed: LED66.2 (DIN), Q73.3 (D), R79.2
unnamed: LED66.3 (DOUT), LED67.2 (DIN)
unnamed: LED67.3 (DOUT), LED68.2 (DIN)
unnamed: LED60.1, Q60.3 (D)
unnamed: LED61.1, Q61.3 (D)
unnamed: LED62.1, Q62.3 (D)
unnamed: LED63.1, Q63.3 (D)
unnamed: LED64.1, Q64.3 (D)
unnamed: LED65.1, Q65.3 (D)

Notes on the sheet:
Lötfeld 2: Fingerfertigkeit
FABLAB Winti - Lötkurs Praxis 2

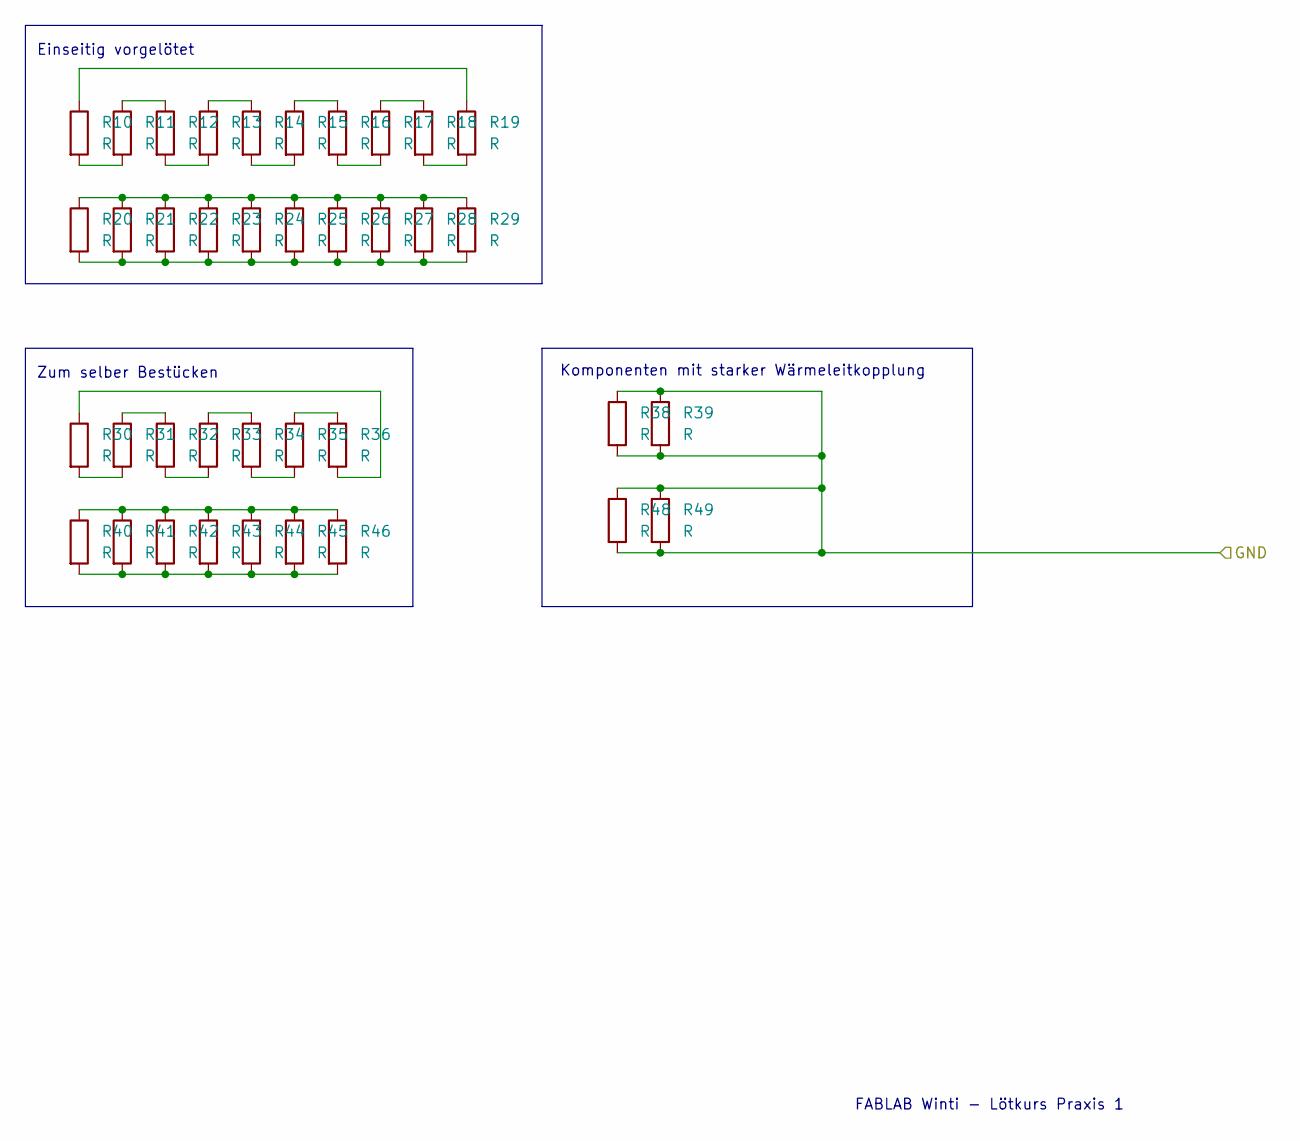
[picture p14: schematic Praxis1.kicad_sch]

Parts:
R10, R11, R12, R13, R14, R15, R16, R17, R18, R19, R30, R31, R32, R33, R34, R35, R36, R38, R39: R; R_1206_3216Metric
R20, R21, R22, R23, R24, R25, R26, R27, R28, R29, R40, R41, R42, R43, R44, R45, R46, R48, R49: R; R_0805_2012Metric

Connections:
GND: R38.1, R38.2, R39.1, R39.2, R48.1, R48.2, R49.1, R49.2; also elsewhere on the board
unnamed: R10.1, R19.1
unnamed: R10.2, R11.2
unnamed: R11.1, R12.1
unnamed: R12.2, R13.2
unnamed: R13.1, R14.1
unnamed: R14.2, R15.2
unnamed: R15.1, R16.1
unnamed: R16.2, R17.2
unnamed: R17.1, R18.1
unnamed: R18.2, R19.2
unnamed: R20.1, R21.1, R22.1, R23.1, R24.1, R25.1, R26.1, R27.1, R28.1, R29.1
unnamed: R20.2, R21.2, R22.2, R23.2, R24.2, R25.2, R26.2, R27.2, R28.2, R29.2
unnamed: R30.1, R36.2
unnamed: R30.2, R31.2
unnamed: R31.1, R32.1
unnamed: R32.2, R33.2
unnamed: R33.1, R34.1
unnamed: R34.2, R35.2
unnamed: R35.1, R36.1
unnamed: R40.1, R41.1, R42.1, R43.1, R44.1, R45.1, R46.1
unnamed: R40.2, R41.2, R42.2, R43.2, R44.2, R45.2, R46.2

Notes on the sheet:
Einseitig vorgelötet
Komponenten mit starker Wärmeleitkopplung
FABLAB Winti - Lötkurs Praxis 1
Zum selber Bestücken

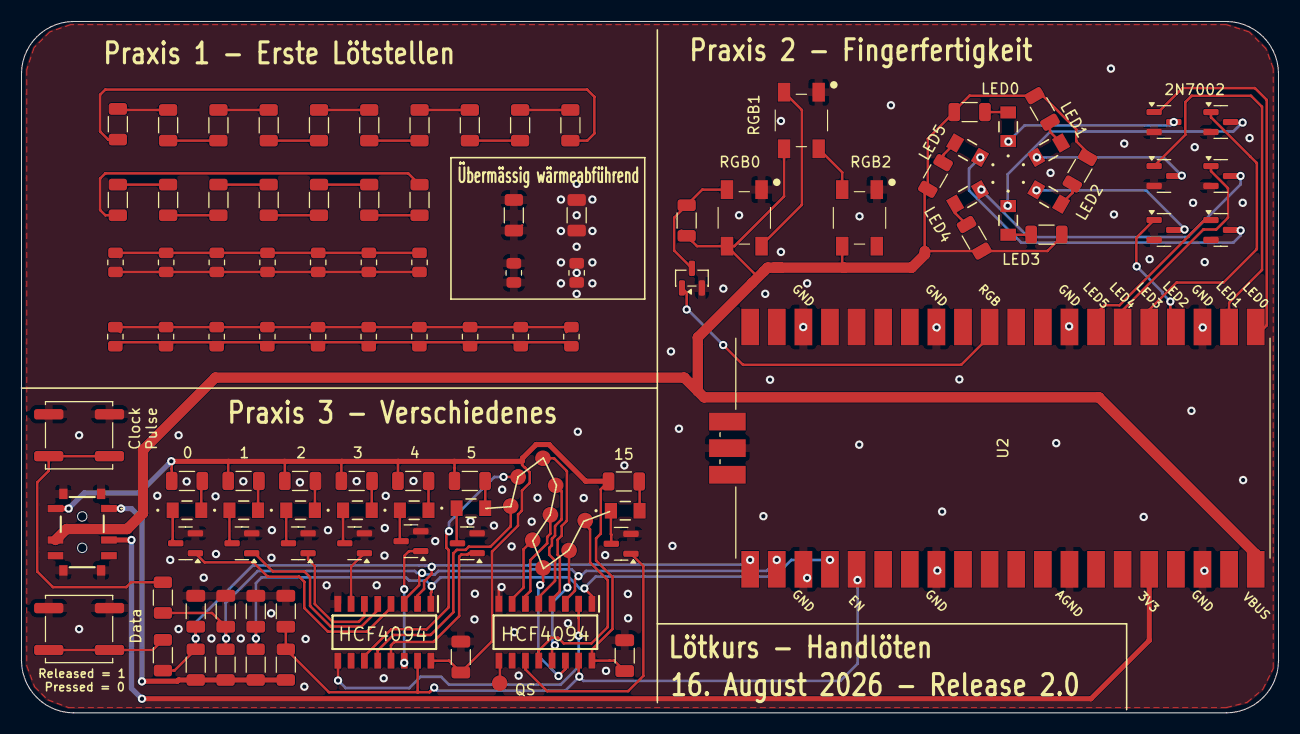
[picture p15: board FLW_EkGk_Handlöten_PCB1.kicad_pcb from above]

Board: 2 copper layers, 120.0 x 66.0 mm, 110 parts (0 on the bottom side), 86 nets.

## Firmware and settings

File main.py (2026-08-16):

import array
import rp2
from machine import Pin
from time import sleep_ms, ticks_ms, ticks_diff
import uasyncio as asyncio
import math


# ============================================================
# Configuration parameters
# ============================================================

NUM_LEDS = 3                    # Number of WS2812 LEDs
WS2812_PIN_NUM = 8              # GPIO pin connected to WS2812

NUM_DEBUG_LEDS = 6              # Number of debug LEDs
DEBUG_PIN_NUMS = [0, 1, 2, 3, 4, 5]

BRIGHTNESS_PERIOD_MS = 10 * 1000  # Full brightness cycle: 10 seconds


# ============================================================
# WS2812 PIO program
# ============================================================

@rp2.asm_pio(
    sideset_init=rp2.PIO.OUT_LOW,
    out_shiftdir=rp2.PIO.SHIFT_LEFT,
    autopull=True,
    pull_thresh=24
)
def ws2812():
    T1 = 2
    T2 = 5
    T3 = 3

    wrap_target()

    label('bitloop')

    out(x, 1).side(0) [T3 - 1]
    jmp(not_x, 'do_zero').side(1) [T1 - 1]
    jmp('bitloop').side(1) [T2 - 1]

    label('do_zero')
    nop().side(0) [T2 - 1]

    wrap()


# ============================================================
# Create WS2812 StateMachine
# ============================================================

sm = rp2.StateMachine(
    0,
    ws2812,
    freq=8_000_000,
    sideset_base=Pin(WS2812_PIN_NUM)
)

sm.active(1)


# ============================================================
# Debug LEDs
# ============================================================

debug_leds = [
    Pin(pin_num, Pin.OUT)
    for pin_num in DEBUG_PIN_NUMS
]


# ============================================================
# Pico onboard LED
# ============================================================

# "LED" automatically refers to the onboard LED on the Pico.
# This works on the standard Raspberry Pi Pico/Pico W
# MicroPython builds that expose the onboard LED this way.

pico_led = Pin("LED", Pin.OUT)


# ============================================================
# WS2812 functions
# ============================================================

def ws2812_write(led_data):
    """
    Send color data to the WS2812 LEDs.
    """

    ar = array.array("I", led_data)

    sm.put(ar, 8)

    # Short delay to ensure the data is latched
    sleep_ms(1)


def rgb_to_grb(r, g, b):
    """
    Convert RGB values to the GRB format required by WS2812.
    """

    return (g << 16) | (r << 8) | b


# ============================================================
# HSV to RGB conversion
# ============================================================

def hsv_to_rgb(hue, saturation, value):
    """
    Convert HSV values to RGB.

    hue:
        0.0 - 1.0

    saturation:
        0.0 - 1.0

    value:
        0.0 - 1.0
    """

    if saturation == 0.0:
        return (value, value, value)

    i = int(hue * 6.0)

    f = (hue * 6.0) - i

    p = value * (1.0 - saturation)

    q = value * (1.0 - (saturation * f))

    t = value * (
        1.0 - (saturation * (1.0 - f))
    )

    i = i % 6

    if i == 0:
        return (value, t, p)

    if i == 1:
        return (q, value, p)

    if i == 2:
        return (p, value, t)

    if i == 3:
        return (p, q, value)

    if i == 4:
        return (t, p, value)

    if i == 5:
        return (value, p, q)


# ============================================================
# Comet effect for GPIO 0-5
# ============================================================

async def comet_effect():

    tail_length = 3

    delay = 100  # milliseconds

    while True:

        for i in range(NUM_DEBUG_LEDS):

            # Turn off all debug LEDs
            for led in debug_leds:
                led.off()

            # Light up the comet tail
            for j in range(tail_length):

                index = (
                    i - j + NUM_DEBUG_LEDS
                ) % NUM_DEBUG_LEDS

                debug_leds[index].on()

            # Wait before moving the comet
            await asyncio.sleep_ms(delay)


# ============================================================
# WS2812 smooth color transition
# ============================================================

async def smooth_color_transition_with_oscillating_brightness():

    # Different starting hue for each WS2812
    start_hues = [
        0.0,
        0.33,
        0.67
    ]

    # Update interval
    delay = 50

    # Record starting time
    start_time = ticks_ms()

    while True:

        current_time = ticks_ms()

        elapsed_time = ticks_diff(
            current_time,
            start_time
        )

        # ----------------------------------------------------
        # Oscillating brightness
        #
        # Goes smoothly:
        # 0 -> 1 -> 0
        #
        # over BRIGHTNESS_PERIOD_MS
        # ----------------------------------------------------

        brightness = (
            math.sin(
                2 * math.pi *
                (
                    elapsed_time /
                    BRIGHTNESS_PERIOD_MS
                )
            ) + 1
        ) / 2

        # List containing colors for all WS2812 LEDs
        led_colors = []

        for i, start_hue in enumerate(start_hues):

            # Continuously rotate through the hue spectrum
            hue = (
                start_hue +
                (elapsed_time / 255.0)
            ) % 1.0

            # Convert HSV to RGB
            r, g, b = hsv_to_rgb(
                hue,
                1.0,
                brightness
            )

            # Convert 0.0-1.0 RGB to 0-255
            r = int(r * 255)
            g = int(g * 255)
            b = int(b * 255)

            # Convert RGB to WS2812 GRB format
            grb_color = rgb_to_grb(
                r,
                g,
                b
            )

            led_colors.append(grb_color)

        # Send colors to WS2812 LEDs
        ws2812_write(led_colors)

        # Wait before next update
        await asyncio.sleep_ms(delay)


# ============================================================
# Pico onboard LED blink
# ============================================================

async def blink_pico_led():

    while True:

        # Turn onboard LED ON
        pico_led.on()

        # Keep it on for 500 ms
        await asyncio.sleep_ms(500)

        # Turn onboard LED OFF
        pico_led.off()

        # Keep it off for 500 ms
        await asyncio.sleep_ms(500)


# ============================================================
# Main asynchronous function
# ============================================================

async def main():

    # Run all three effects concurrently
    await asyncio.gather(

        # GPIO 0-5 comet effect
        comet_effect(),

        # WS2812 color/brightness effect
        smooth_color_transition_with_oscillating_brightness(),

        # Pico onboard LED blinking
        blink_pico_led()
    )


# ============================================================
# Start everything
# ============================================================

asyncio.run(main())

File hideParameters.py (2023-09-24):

import os
import fileinput

def search_and_modify(file_name, search_string):
    file_path = os.path.abspath(file_name)
    modified = False

    for line in fileinput.input(file_path, inplace=True):
        # Remove trailing whitespace and check if line ends with "hide"
        stripped_line = line.strip()
        if stripped_line.endswith("hide"):
            print(line, end='')  # Line already has "hide", don't modify
        elif search_string in line:
            # If the search string is found, add " hide" to the end of the line
            print(line.rstrip() + " hide")
            modified = True
        else:
            print(line, end='')

    if modified:
        print("Changes have been made to the file.")
    else:
        print("No changes were made to the file.")

if __name__ == "__main__":
    search_string = input("Enter the string to search for: ")
    kicad_pcb_file = input("Enter the PCB file name (in the same directory as the script): ")

    search_and_modify(kicad_pcb_file, search_string)

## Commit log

2023-09-23 asdf
    asdf
    [FLW_EkGk_Handlöten_PCB1.kicad_pcb, FLW_EkGk_Handlöten_PCB1.kicad_sch, Praxis1.kicad_sch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]
2023-11-06 Almost finished
    [FLW_EkGk_Handlöten_PCB1.kicad_pcb, FLW_EkGk_Handlöten_PCB1.kicad_sch, Praxis3.kicad_sch]
2023-11-06 Cleaned up some warnings
    [FLW_EkGk_Handlöten_PCB1.kicad_pcb]
2023-11-21 Removed Aisler Tag
    [FLW_EkGk_Handlöten_PCB1.kicad_pcb]
2023-11-21 Last changes
    [FLW_EkGk_Handlöten_PCB1.kicad_pcb, Praxis3.kicad_sch]
2024-02-29 Resolves #1: increased footprint solder mask to get better access with the solder tip
    [FLW_EkGk_Handlöten_PCB1.kicad_pcb]
2024-03-01 Resolves #2: Added current limiting resistor values (i.e. 620 Ohm)
    [FLW_EkGk_Handlöten_PCB1.kicad_pcb, FLW_EkGk_Handlöten_PCB1.kicad_sch, Praxis1.kicad_sch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]
2024-05-31 updated BOM-Ptouch Etikett, added 620R
2024-09-02 Resolves #3: Missing Pin Marks
    [FLW_EkGk_Handlöten_PCB1.kicad_pcb]
2025-03-04 Added Soldering Equipment
2026-01-13 Added C for all digital signals
    [FLW_EkGk_Handlöten_PCB1.kicad_pcb, FLW_EkGk_Handlöten_PCB1.kicad_sch, Praxis1.kicad_sch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]
2026-04-08 update to kicad 10
    [FLW_EkGk_Handlöten_PCB1.kicad_sch, Praxis1.kicad_sch, Praxis2.kicad_sch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]
2026-08-16 resolved RGB issue
    [FLW_EkGk_Handlöten_PCB1.kicad_pcb, FLW_EkGk_Handlöten_PCB1.kicad_sch, Praxis1.kicad_sch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]
2026-10-07 added stuff
    [Praxis3.kicad_sch]
